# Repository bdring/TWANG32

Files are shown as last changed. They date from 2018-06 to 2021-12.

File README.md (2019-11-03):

# TWANG32
An ESP32 based, 1D, LED strip, dungeon crawler. inspired by Line Wobbler by Robin B

This was ported from the [TWANG fork](https://github.com/bdring/TWANG) by bdring of [Buildlog.net Blog](http://www.buildlog.net/blog?s=twang)

Youtube Video (https://www.youtube.com/watch?v=RXpfa-ZvUMA)

TWANG LED Game

## Why ESP32?
- Lower Cost than Arduino Mega
- Faster Processor
- More Memory
- Smaller (allows a smaller enclosure that is easier to print and more portable)
- DAC pins for better sound capabilities.
- WiFi and Bluetooth.

**Current State**

- All of the Arduino version game features are functional.
- The game now has a WiFi access port to get game stats. Connect a smartphone or computer to see them.
  - **SSID:** TWANG_AP
  - **Password:** 12345666
  - **URL:** 192.168.4.1
- You can update these settings over WiFi
  - LED Count
  - LED Brightness
  - Audio Volume
  - Joystick Deadzone (removes drift)
  - Attack Threshold (twang sensitivity)
  - Lives Per Level



## TO DO List:

- Wireless features~~
  - 2 Player features by linking controllers. TBD
=======
-  Settings:
  - Change strip type.
-  Digitized Audio
  - Currently the port uses the same square wave tones of the the Arduino version.
  - I want to convert to digitized high quality sound effects.
  - Possibly mix multiple sounds so things like lava and movement sound good at the same time.
- Better looking mobile web interface (looks more like a web app)

**BTW:** Since you have red this far... If you want to contribute, contact me and I might be able to get you some free or discounted hardware.

## Required libraries:
* [FastLED](http://fastled.io/)
* [RunningMedian](http://playground.arduino.cc/Main/RunningMedian)

## Hardware used:
* ESP32, I typically use the NodeMCU-32S module
* LED light strip. The more the better, maximum of 1000. Tested with 1x & 2x 144/meter, 12x 60/meter and 5m x 114/meter strips. This has been tested with APA102C and NeoPixel type strips. Anything compatible with the FastLED library should work.
* MPU6050 accelerometer
* Spring doorstop, I used [these](http://smile.amazon.com/gp/product/B00J4Y5BU2)
* Speaker and amplifier. I use a PAM8403 module. (ESP32 cannot drive a speaker as loudly as an Arduino)

See [Buildlog.net Blog](http://www.buildlog.net/blog?s=twang) for more details.

Super easy to use kits and ready to play units [are available on Tindie](https://www.tindie.com/products/33366583/twang32-led-strip-game/).

TWANG 32 Controller

## Enclosure
[The STL files are here](http://www.buildlog.net/blog/wp-content/uploads/2018/04/twang32_stl.zip).

TWANG32

## Overview
The following is a quick overview of the code to help you understand and tweak the game to your needs.

The game is played on a 1000 unit line, the position of enemies, the player, lava etc range from 0 to 1000 and the LEDs that represent them are derived using the `getLED()` function. You don't need to worry about this but it's good to know for things like the width of the attack and player max move speed. Regardless of the number of LEDs, everything takes place in this 1000 unit wide line.

**LED SETUP** Defines the quantity of LEDs as well as the data and clock pins used. I've tested several APA102-C strips and the color order sometimes changes from BGR to GBR, if the player is not blue, the exit green and the enemies red, this is the bit you want to change. Brightness should range from 50 to 255, use a lower number if playing at night or wanting to use a smaller power supply. `DIRECTION` can be set to 0 or 1 to flip the game orientation. In `setup()` there is a `FastLED.addLeds()` line, in there you could change it to another brand of LED strip like the cheaper WS2812.

The game also has 3 regular LEDs for life indicators (the player gets 3 lives which reset each time they level up). The pins for these LEDs are stored in `lifeLEDs[]` and are updated in the `updateLives()` function.

**JOYSTICK SETUP** All parameters are commented in the code, you can set it to work in both forward/backward as well as side-to-side mode by changing `JOYSTICK_ORIENTATION`. Adjust the `ATTACK_THRESHOLD` if the "Twanging" is overly sensitive and the `JOYSTICK_DEADZONE` if the player slowly drifts when there is no input (because it's hard to get the MPU6050 dead level).

**WOBBLE ATTACK** Sets the width, duration (ms) of the attack.

**POOLS** These are the object pools for enemies, particles, lava, conveyors etc. You can modify the quantity of any of them if your levels use more or if you want to save some memory, just remember to update the respective counts to avoid errors.

**USE_GRAVITY** 0/1 to set if particles created by the player getting killed should fall towards the start point, the `BEND_POINT` variable can be set to mark the point at which the strip of LEDs goes from being horizontal to vertical. The game is 1000 units wide (regardless of number of LED's) so 500 would be the mid point. If this is confusing just set `USE_GRAVITY` to 0.

## Modifying / Creating levels
Find the `loadLevel()` function, in there you can see a switch statement with the 10 levels I created.
They all call different functions and variables to setup the level. Each one is described below:

**playerPosition;** Where the player starts on the 0 to 1000 line. If not set it defaults to 0. I set it to 200 in the first level so the player can see movement even if the first action they take is to push the joystick left

**spawnEnemy(position, direction, speed, wobble);** (10 enemies max)
* position: 0 to 1000
* direction: 0/1, initial direction of travel
* speed: >=0, speed of the enemy, remember the game is 1000 wide and runs at 60fps. I recommend between 1 and 4
* wobble: 0=regular moving enemy, 1=sine wave enemy, in this case speed sets the width of the wave

**spawnPool[poolNumber].Spawn(position, rate, speed, direction);** (2 spawners max)
* A spawn pool is a point which spawns enemies forever
* position: 0 to 1000
* rate: milliseconds between spawns, 1000 = 1 second
* speed: speed of the enemis it spawns
* direction: 0=towards start, 1=away from start

**spawnLava(startPoint, endPoint, ontime, offtime, offset);** (4 lava pools max)
* startPoint: 0 to 1000
* endPoint: 0 to 1000, combined with startPoint this sets the location and size of the lava
* ontime: How long (ms) the lava is ON for
* offtime: How long the lava is ON for
* offset: How long (ms) after the level starts before the lava turns on, use this to create patterns with multiple lavas
* grow: This specifies the rate of growth. Use 0 for no growth. Reasonable growth is 0.1 to 0.5
* flow: This specifies the rate/direction of flow. Reasonable numbers are 0.2 to 0.8 

**spawnConveyor(startPoint, endPoint, speed);** (2 conveyors max)
* startPoint, endPoint: Same as lava
* speed: The direction and speed of the travel. Negative moves to base and positive moves towards exit. Must be less than +/- max player speed.

**spawnBoss();** (only one, don't edit boss level)
<<<<<<< HEAD
* There are no parameters for a boss, they always spawn in the same place and have 3 lives. Tweak the values of Boss.h to modify
=======
* There are no parameters for a boss, they always spawn in the same place and have 3 lives. Tweak the values of Boss.h to modify
>>>>>>> origin/master

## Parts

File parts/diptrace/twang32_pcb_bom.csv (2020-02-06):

RefDes | Value | Name | Manufacturer | Quantity
C1 | 1000uF 10V | UCL_size10x13.5 | Nichicon UCL1A102MNL1GS | 1
C2 | 0.47uF | CAP_NP_1206 |  | 1
C3 | 0.1uF | CAP_NP_1206 |  | 1
C4, C5, C8 | 1uF | CAP_NP_1206 |  | 3
C6, C7 | 10uF | CAP_NP_1206 |  | 2
D1 |  | 10BQ100 | Vishay SS2P2L-M3/84A | 1
J1 |  | PJ-007 | CUI | 1
J2 |  | HDR-1x2 |  | 1
R1, R2 | 10K | RES_1206 |  | 2
R3 | 1.5K | RES_1206 |  | 1
TB1, TB2 |  | TB_3p5mm_4POS |  | 2
U1 | ESP-32 | ESP-32 NodeMCU 32S |  | 1
U2 |  | PAM8403 | Diodes Inc | 1

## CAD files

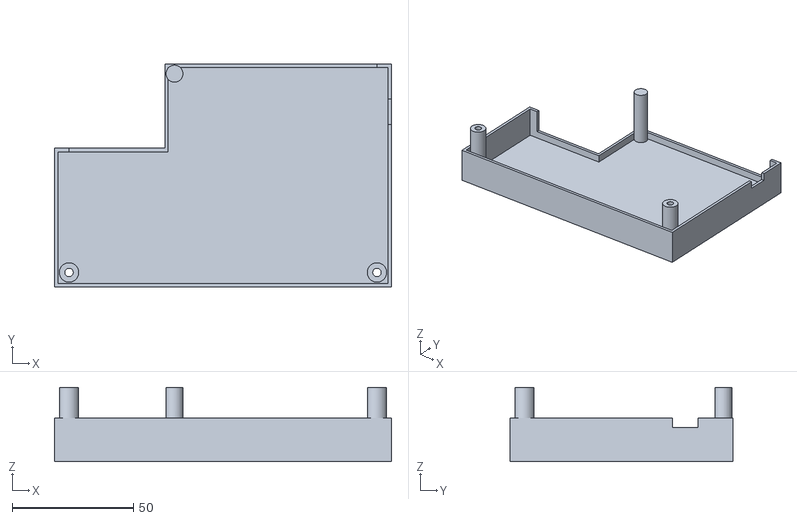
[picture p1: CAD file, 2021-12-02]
parts/stl/6_pack_cover_top.stl
139.0 x 92.0 x 30.6

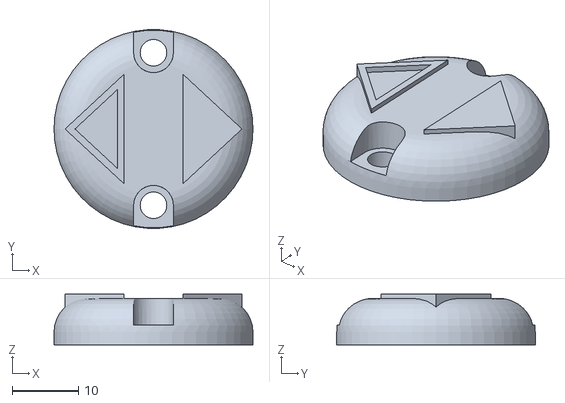
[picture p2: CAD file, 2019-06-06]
parts/stl/knob_cap2.stl
30.0 x 29.9 x 7.62

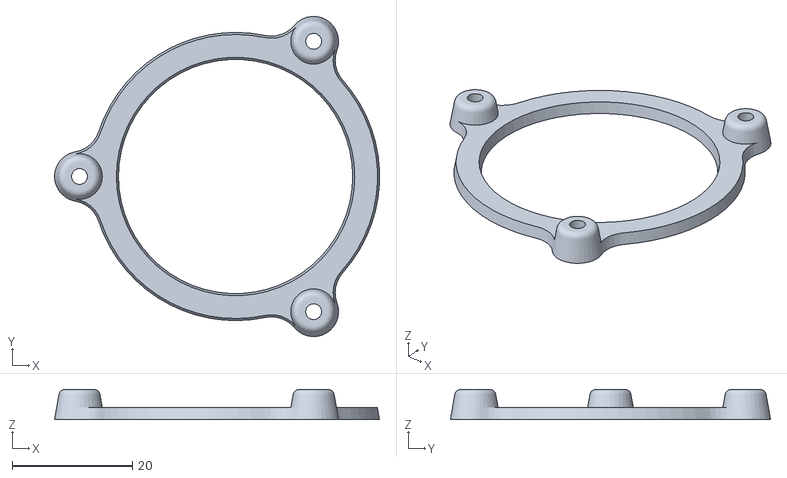
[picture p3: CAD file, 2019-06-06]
parts/stl/twang32_speaker_clamp.stl
54.1 x 53.3 x 5.00

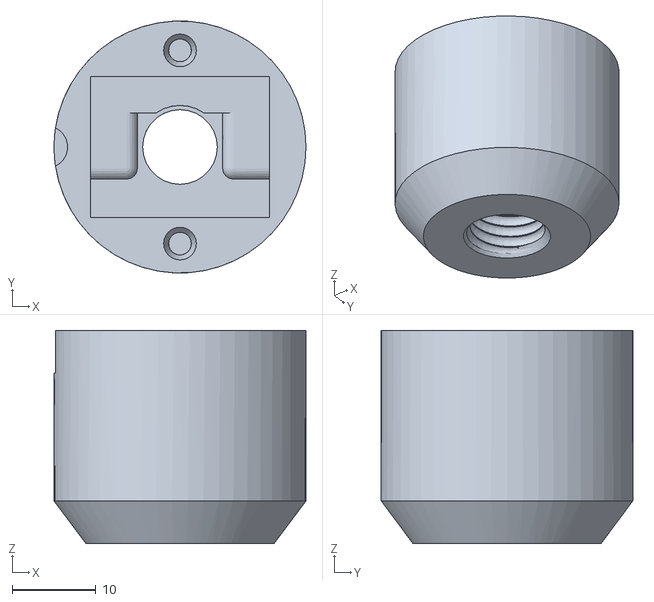
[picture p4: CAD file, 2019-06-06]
parts/stl/knob_bottom_2.stl
30.0 x 30.0 x 25.4

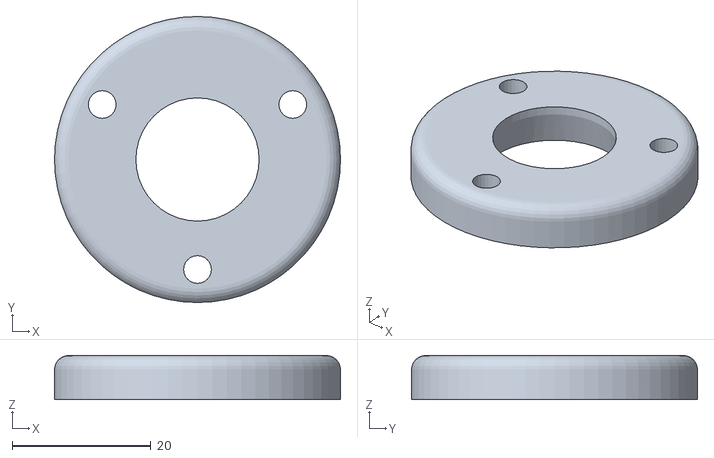
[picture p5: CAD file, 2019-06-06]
parts/stl/spring_clamp.stl
41.3 x 41.3 x 6.35

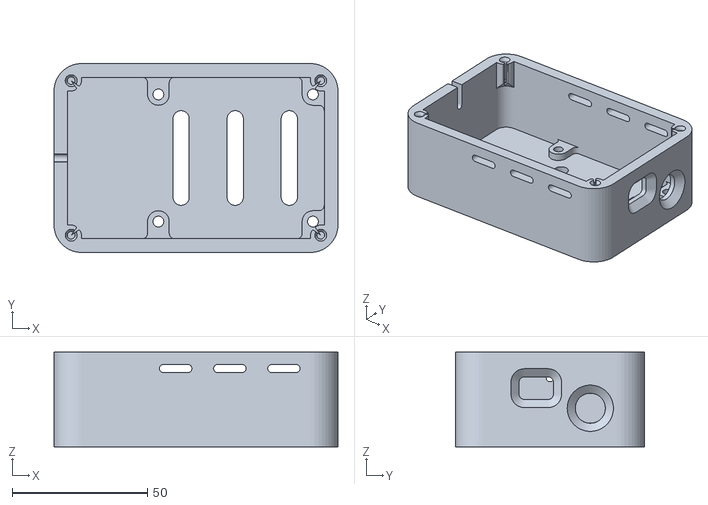
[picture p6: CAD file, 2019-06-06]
parts/stl/twang32_chassis.stl
105.0 x 69.8 x 35.0

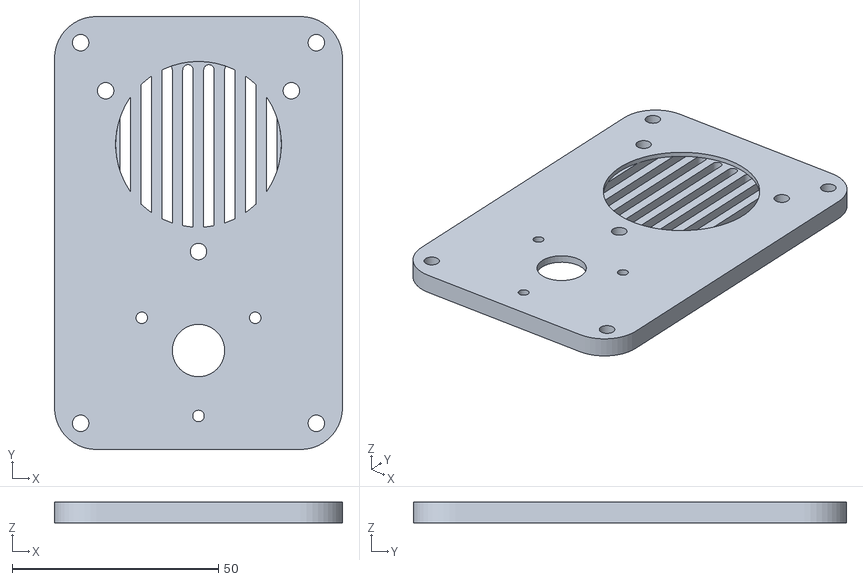
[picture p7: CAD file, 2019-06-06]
parts/stl/twang32_cover_2.stl
69.8 x 105.0 x 5.08

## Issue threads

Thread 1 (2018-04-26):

FastLED issue

sandman72, 2018-04-26:
The current official FastLED 3.1.6 library seems to cause watchdog reset issues here in my ESP32 setup (TTGO 32 R1 board, ESP32 rev1, Arduino ESP32 from Februray). I tried a workaround turning off interrupts during the FastLED .show() call with:

#define FASTLED_ALLOW_INTERRUPTS 0

but unfortunatly that breaks the sound output (loads of clickings during LED updates).
Could you check which versions of the Arduino Core ESP32 and FastLED libraries you are using, assuming everthing is working for you?

BTW: Awesome work! 😃

buildlog, 2018-04-26:
Sorry to hear you are having problems.

I am using FastLED 3.1.6. I am not sure how to tell the exact version of the ESP32 core, but my latest files are dated 3/14/2018. It runs fine for me on board NodeMCU-32S.  I have compiled it on several computers without issue. I don't know what happens when you choose different boards. What board are you compiling for? Did you change anything else in the firmware, like the #defines for the pins?

The only issue I had during development is that I had to turn off all Interrupts during EEPROM commits.

BTW: I am working on an ESP32 port of Grbl and am having problems with watchdog resets during interrupts. I have not solved that yet.

sandman72, 2018-04-27:
No, worries... WDT resets are quite common... usually a yield(); here and there will solve that... ;)
I had that issue with the FastLED library on the ESP32 before and could only get it to work stable with turning off interrupts... That usually breaks something else, in this case the sound part. I'll have a look over the weekend if I can find something...

sandman72, 2018-05-06:
I can confirm that this only happens with WS2812b based strips and their timing requirements. The APA102 strips work fine. No sound issues if you use these. For more infos: https://github.com/FastLED/FastLED/wiki/Interrupt-problems

afreeland, 2019-10-23:
I am using W2812B LEDs (300 count 16.4') and noticing what appears to be intermittent "freezing" of accelerometer data.  As in, the LEDs and game continue but the input from 🕹️ no longer seems to move the green dot... Until a hard power down.  Also the sound kind of had a pulsing/ticking that is always happening.

Was just curious if the interrupt issue would manifest itself in either of those ways?

Also I am using the esp-wroom-32 DoIt devkit v1 board, if that helps.

Hoping you may have some guidance here, thanks!

Closed 2018-05-06.

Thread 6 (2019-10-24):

Conveyor belt not working and lava not working properly..

yuppicide, 2019-10-24:
So I received my Twang32 prebuilt from you except for the LED wire. We tested it out using two APA102's. I adjusted brightness, sound volume, attack sensitivity, and 288 LED's. It was working fine. My friends had a blast with it!

I took it home and played a game or two and it was working fine. However, later that night I came back and the conveyor belt did not light up (invisible/lights off) but it still functions properly (pushes you backwards). The lava doesn't look like it used to. Instead of twinkling when it's safe to cross, it does not light up (invisible/lights off) but still functions properly (kills me).

Any ideas what is wrong here?

(Also, side note.. how come my lives (and your video on YouTube) show the lives on the bottom next to the controller, but this guy https://www.youtube.com/watch?v=pCQsKuKeDGg his is at the top of the LED strip)

yuppicide, 2019-10-24:
PS - I  have already tried recompiling and I have 2 more LED strips I tested. Same issue.. no conveyor or lava.

bdring, 2019-10-24:
Try increasing the brightness to full, just as a test.

yuppicide, 2019-10-25:
Already figured it out. I wish I would have figured it out before posting a
bug. 35 brightness shows.. I'm not sure the exact number but 25 definitely
doesn't show.

I was playing in the house and didn't wanna bother anyone is why I had it
down.

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

bdring, 2019-10-25:
I have seen that on WS2812 strips, but not on APA102 strips, so i guessed that might be it. The brightness is a global thing and some of the lighter items drop out first.

In [config.h](https://github.com/bdring/TWANG32/blob/master/TWANG32/config.h#L50) you will see some compensation values for the strip types. These were chosen for the strips I tested. You could tweak those values if need be.

bdring, 2019-10-25:
Also, you will probably never be able to use the full range of the brightness on all strip types. Something will drop out first.

Closed 2019-10-25.

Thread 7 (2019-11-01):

Accelerometer data freezes

afreeland, 2019-11-01:
I have been seeing an issue where, what appears to be randomly, the accelerometer data just stops working with the game. The green LED player will just stop moving...all other neopixel leds still work (enemies move, lava flows, death animation works, random led sequence post game). Once the game stops accepting accelerometer input, nothing seems to fix it but a hard power reboot.  I have triple checked the cabling to ensure no shorts...tried various accelerometer chips but with no luck.

I seen another [issue on interrupts](https://github.com/bdring/TWANG32/issues/1#issuecomment-545228889) and was sure if that was related or not.  Just looking for any guidance on how to test or if you have seen this issue.

Hardware:
- DOIT Esp32 DevKit v1 board
- [WS2812B](https://www.amazon.com/gp/product/B01LSF4Q0A/ref=ppx_yo_dt_b_asin_title_o04_s01?ie=UTF8&psc=1) NeoPixels
- [MPU6050](https://www.amazon.com/gp/product/B00LP25V1A/ref=ppx_yo_dt_b_asin_title_o03_s00?ie=UTF8&psc=1)

I did see the debug lines for serial and will try that...I mounted LEDs to a wall already and it makes the reading of serial a little trickier now.  I probably should of worked out the kinks before going all in lol :)
https://github.com/bdring/TWANG32/blob/0ef73584328d7b5b7d4b6bc1e1dc2b60e992db4c/TWANG32/TWANG32.ino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

bdring, 2019-11-02:
I have seen lock ups, but quite rarely. I can have it running for hours without issue.

I wonder if you go a few loops without proper data, the gyro could be re-initialized

```C++
accelgyro.initialize();
```

I have not played with the code in a while, but recently thought of some new level ideas. I thought some lava options could be tried. If it flowed or grew, it could create some urgency to complete levels.  I might give another look at the accel code then.

afreeland, 2019-11-02:
Thanks for the response and will look into the `initialize()` code.  I wish I wasn't so garbage at c/c++ or I could help...if this was like C#, JS, Go, Python...anything else lol.  I am just so terribly slow with c++.

The Lava _flowing_ sounds like a really cool improvement and forcing urgency would be a great addition.

You ever noticed any feedback to audio from wifi?  I am using [Adafruit Mono 2.5w amp](https://www.adafruit.com/product/2130) and have noticed that I get this constant ticking audio.  I see the blips in the oscilliscope and I cant seem to track down what is causing it...I put my finger over the wireless antenna and noticed that the _ticking_ was greatly reduced (barely audible).  They are side by side on the board and thought that may be causing me some issues.

bdring, 2019-11-02:
I have not heard any ticking sounds. Try switching DAC outputs. How wide is the tick on the scope? Could you filter it? I use the [PAM8403](https://www.aliexpress.com/item/1822706737.html)

I think an early level with lava moving down would be a good introduction. Lava growing from the bottom would be a great way to push you along. Lava growing in the middle would eventually be to wide to cross and force death near the bottom.

afreeland, 2019-11-02:
> I have not heard any ticking sounds. Try switching DAC outputs. How wide is the tick on the scope? Could you filter it? I use the [PAM8403](https://www.aliexpress.com/item/1822706737.html)
>
> I think an early level with lava moving down would be a good introduction. Lava growing from the bottom would be a great way to push you along. Lava growing in the middle would eventually be to wide to cross and force death near the bottom.

So was just doing some serial monitor debugging and trying to identify the issues with the accelerometer.  I got distracted by the ticking sound and swapped out DAC pin 25 for 26 and was still hearing it.  I was really suspicious of the wifi module since when I press on the antenna the ticking almost disappears.

Commented out this line just to try: https://github.com/bdring/TWANG32/blob/master/TWANG32/TWANG32.ino#L226

Sure enough the ticking is now gone but so would my webserver.  I may throw a different esp32 at it and see if that helps and when I build the stand for the twang stick I may put some distance between the audio amp/speaker and the board.  Just figured I would give an update on that very strange issue.  Not sure if its an interference issue or something with how the wifi lib operates...but I am guessing interference since you have not seen that issue.

bdring, 2019-11-02:
Thanks for the update. Nice job isolating it to the wifi.

I will probably start looking at the accel and lava code on Monday.

bdring, 2019-11-02:
If you turn of the serial debugging and have a screen lockup. Tell me what the values are.

bdring, 2019-11-03:
I got some time and added the flowing and growing lava. It really adds a sense of panic to some levels. I added a few new levels with various implementations.  I'll push the changes tomorrow.

**BTW:** I had it running for about 2 hours while writing and testing with no lockups.

Closed 2020-02-06.

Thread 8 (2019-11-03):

New Lava Features and Levels

bdring, 2019-11-03:
Someone suggested lava could be enhanced, so I added flow and growth parameters. Now the lava can flow at any desired rate and direction. It can also grow in size.

Combined with the on/off times, you can create some **pretty intense levels**. You could place lava at the bottom with a short off time and have it push you towards the top. Lava could also grow at a rate that you need to cross it and get off the level quickly. It can be very distracting to have the lava chasing you from behind and enemies attacking from above.

I added 4 new levels to introduce the features.

Happy Twanging!

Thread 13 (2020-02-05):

Component List

diegotheslinger, 2020-02-05:
Hello, was wondering if anyone knew where to find a component list for this project?  Saw the kit is unavailable from tindie.  I already have the board printed out, just wondering on component sizes as im not super familiar with surface mount packages.

Thank You.

bdring, 2020-02-05:
I can do that in a few days.

diegotheslinger, 2020-02-05:
Wow thank you that would be helpful!

bdring, 2020-02-06:
[Here is what I have](https://github.com/bdring/TWANG32/blob/master/parts/diptrace/twang32_pcb_bom.csv)

Closed 2020-02-06.

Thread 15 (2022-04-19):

Audio only in the first game

zenturacp, 2022-04-19:
Hi - i have created a Twang32 and it works almost the sound is only in the first game...

When I reset the device it works again but never in subsequent games?

zenturacp, 2022-04-21:
https://github.com/bdring/TWANG32/blob/a848394748c9df7516cd4b9a902e994b4a067f36/TWANG32/sound.h#L59

The issue is somehow related to the pause of the audio - it really only is an issue when writing to the EEPROM and it disables the sound / interrupts.. It seems like the sound_resume is not working as expected

It could be related to the ESP32 chip - frequency something?

zenturacp, 2022-04-22:
The issue is "resolved" you have to use ESP32 < version 2.x - 1.0.6 works fine

neilferreri, 2025-01-19:
I fixed this for ESP32 v3.1.1 in my fork.
https://github.com/neilferreri/TWANG32

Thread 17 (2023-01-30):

Low / No gravity jet pack mode?

mylesdebastion, 2023-01-30:
Any interest in adding a node for low / no gravity? Would be happy to sponsor this request!
* create movement mode to make the player (green LED) glide with frictionless inertia to simulate no gravity
* add small flame animation effect like a jet pack behind the green led (flame should switch to front or back when reversing direction of movement)

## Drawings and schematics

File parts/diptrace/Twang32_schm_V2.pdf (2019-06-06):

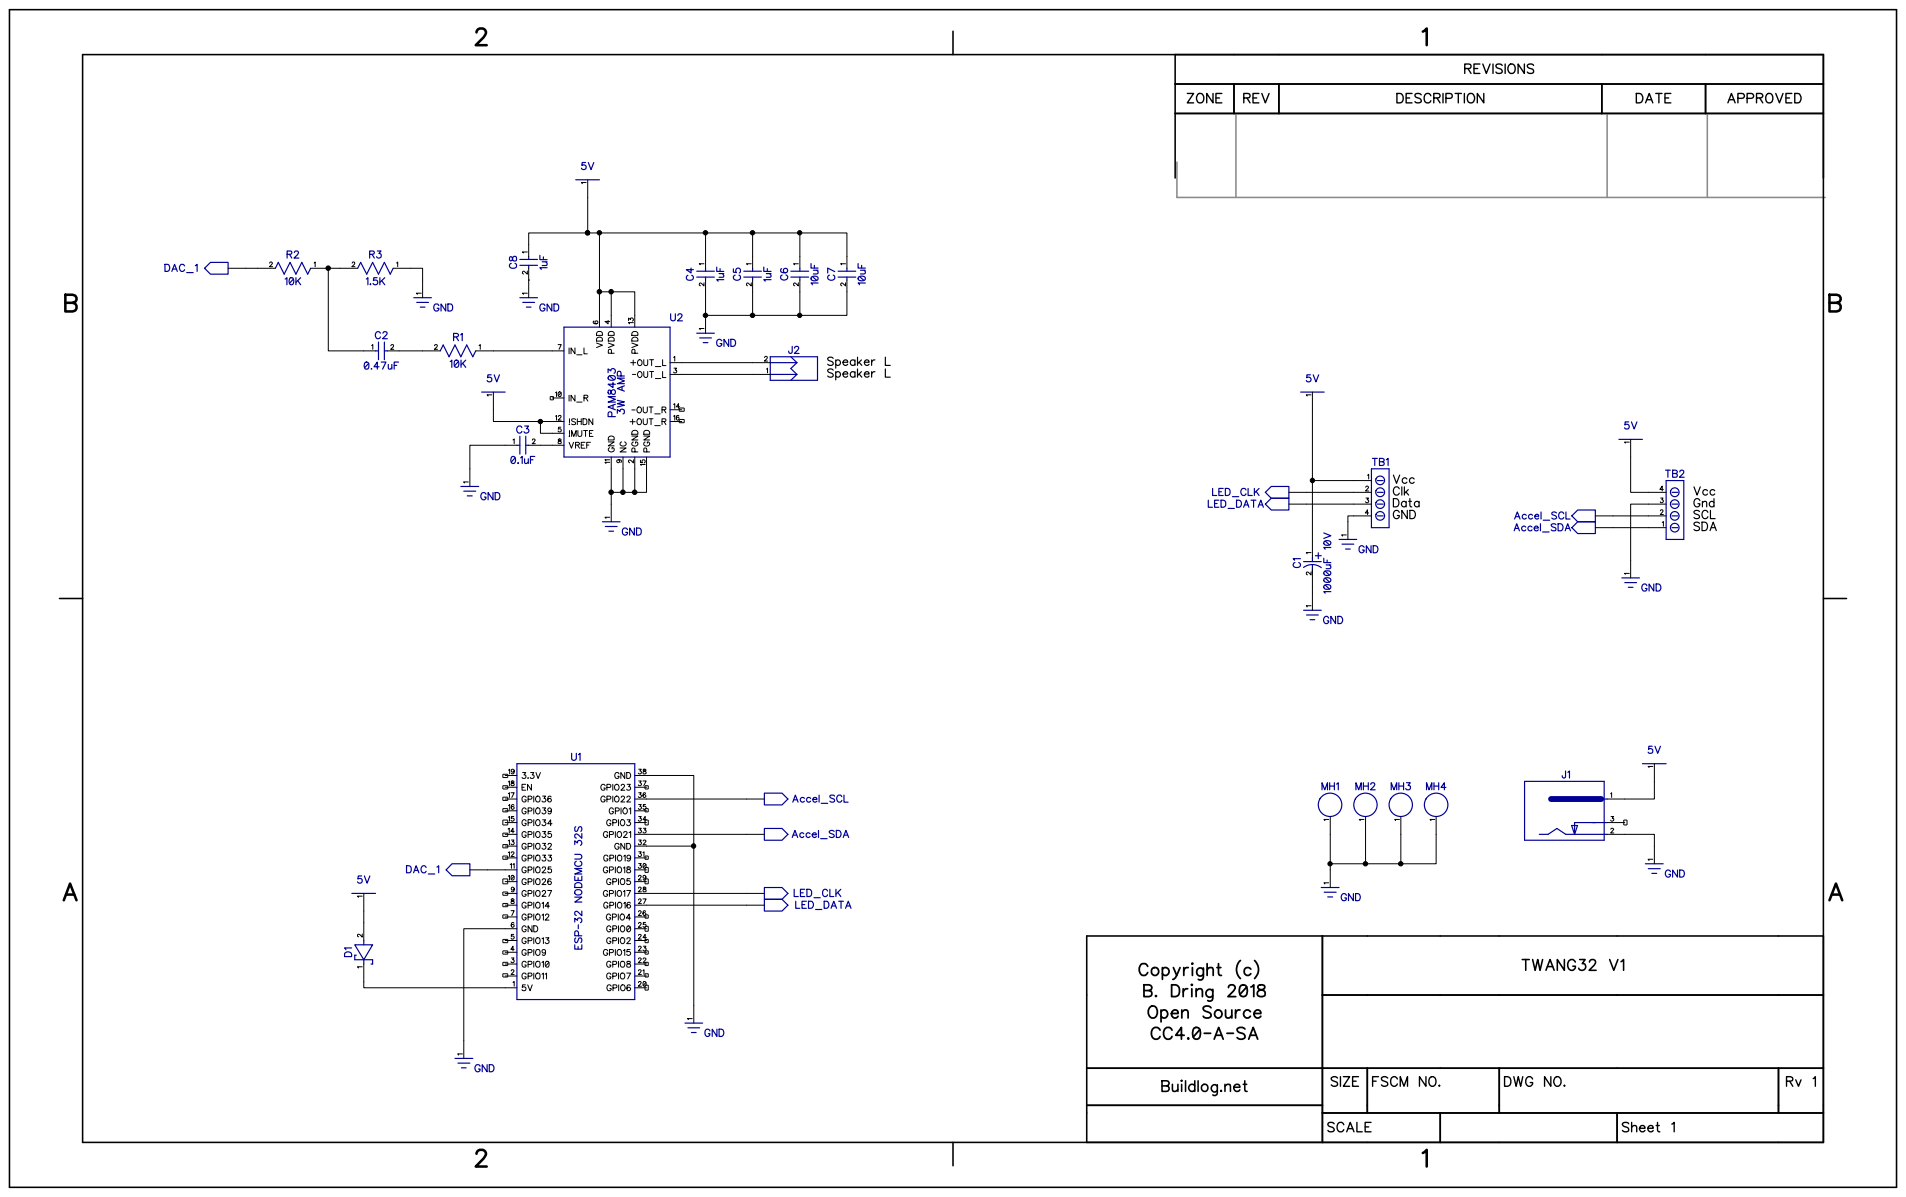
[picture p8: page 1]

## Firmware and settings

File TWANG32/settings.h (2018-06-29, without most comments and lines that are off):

	#define SETTINGS_H
#include <EEPROM.h>
#include "sound.h"
#define SETTINGS_VERSION 2
#define EEPROM_SIZE				   256
#define NUM_LEDS        144
#define MIN_LEDS				60
#define DEFAULT_BRIGHTNESS	150
#define MIN_BRIGHTNESS			10
#define MAX_BRIGHTNESS 			255
const uint8_t MAX_PLAYER_SPEED = 10;     // Max move speed of the player
const uint8_t LIVES_PER_LEVEL = 3;      // default lives per level
#define MIN_LIVES_PER_LEVEL 3
#define MAX_LIVES_PER_LEVEL 9
#define JOYSTICK_ORIENTATION 1     // 0, 1 or 2 to set the axis of the joystick
#define JOYSTICK_DIRECTION   1     // 0/1 to flip joystick direction
#define DEFAULT_ATTACK_THRESHOLD     30000 // The threshold that triggers an attack
#define MIN_ATTACK_THRESHOLD     20000
#define MAX_ATTACK_THRESHOLD     30000
#define DEFAULT_JOYSTICK_DEADZONE    8     // Angle to ignore
#define MIN_JOYSTICK_DEADZONE 3
#define MAX_JOYSTICK_DEADZONE 12
#define DEFAULT_VOLUME          20     // 0 to 255
#define MIN_VOLUME							0
#define MAX_VOLUME							255
#define DAC_AUDIO_PIN 		25     // should be 25 or 26 only
enum ErrorNums{
	ERR_SETTING_NUM,
	ERR_SETTING_RANGE
};
long lastInputTime = 0;
void settings_init();
void show_game_stats();
void settings_eeprom_write();
void settings_eeprom_read();
void change_setting_serial(char *line);
void processSerial(char inChar);
void printError(int reason);
void show_settings_menu();
void reset_settings();
void change_setting(char paramCode, uint16_t newValue);
SemaphoreHandle_t xMutex;
typedef struct {
	uint8_t settings_version; // stores the settings format version
	uint16_t led_count;
	uint8_t led_brightness;
	uint8_t joystick_deadzone;
	uint16_t attack_threshold;
	uint8_t audio_volume;
	uint8_t lives_per_level;
	uint16_t games_played;
	uint32_t total_points;
	uint16_t high_score;
	uint16_t boss_kills;
}settings_t;
settings_t user_settings;
#define READ_BUFFER_LEN 10
#define CARRIAGE_RETURN 13
char readBuffer[READ_BUFFER_LEN];
uint8_t readIndex = 0;
void settings_init() {
	settings_eeprom_read();
	show_settings_menu();
	show_game_stats();
}
void checkSerialInput() {
	if (Serial.available()) {
		processSerial(Serial.read());
	}
}
void processSerial(char inChar)
{
	readBuffer[readIndex] = inChar;
		switch(readBuffer[readIndex]){
			case '?':
				readIndex = 0;
				show_game_stats();
				show_settings_menu();
				return;
			break;
			case 'R':
				readIndex = 0;
				reset_settings();
				settings_eeprom_write();
				return;
			break;
			case 'P':
				user_settings.games_played = 0;
				user_settings.total_points = 0;
				user_settings.high_score = 0;
				user_settings.boss_kills = 0;
				settings_eeprom_write();
				return;
			break;
			case '!':
				ESP.restart();
			default:
			break;
		}
		if (readBuffer[readIndex] == CARRIAGE_RETURN) {
			if (readIndex < 3) {
				readIndex = 0;
			}
			else {
				readBuffer[readIndex] = 0; // mark it as the end of the string
				change_setting_serial(readBuffer);
				readIndex = 0;
			}
		}
		else if (readIndex >= READ_BUFFER_LEN) {
			readIndex = 0; // too many characters. Reset and try again
		}
		else
			readIndex++;
}
void change_setting_serial(char *line) {
  char setting_val[6];
  char param;
  uint16_t newValue;
  if (readBuffer[1] != '='){  // check if the equals sign is there
	Serial.print("Missing '=' in command");
	readIndex = 0;
	return;
  }
  for(int i=0; i<5; i++) {
	if (i+2 < readIndex) {
		if (isDigit(readBuffer[i+2]))
			setting_val[i] = readBuffer[i+2];
		else {
			Serial.println("Invalid setting value");
			return;
		}
	}
	else
		setting_val[i] = 0;
  }
  param = readBuffer[0];
  newValue = atoi(setting_val); // convert the val section to an integer
  memset(readBuffer,0,sizeof(readBuffer));
	change_setting(param, newValue);
}
void change_setting(char paramCode, uint16_t newValue)
{
	switch (paramCode) {
		lastInputTime = millis(); // reset screensaver count
		case 'C': // LED Count
				user_settings.led_count = constrain(newValue, MIN_LEDS, MAX_LEDS);
				settings_eeprom_write();
		break;
		case 'B': // brightness
			user_settings.led_brightness = constrain(newValue, MIN_BRIGHTNESS, MAX_BRIGHTNESS);
			FastLED.setBrightness(user_settings.led_brightness);
			settings_eeprom_write();
		break;
		case 'S': // sound
			user_settings.audio_volume = constrain(newValue, MIN_VOLUME, MAX_VOLUME);
			settings_eeprom_write();
		break;
		case 'D': // deadzone, joystick
			user_settings.joystick_deadzone = constrain(newValue, MIN_JOYSTICK_DEADZONE, MAX_JOYSTICK_DEADZONE);
			settings_eeprom_write();
		break;
		case 'A': // attack threshold, joystick
			user_settings.attack_threshold = constrain(newValue, MIN_ATTACK_THRESHOLD, MAX_ATTACK_THRESHOLD);
			settings_eeprom_write();
		break;
		case 'L': // lives per level
			user_settings.lives_per_level = constrain(newValue, MIN_LIVES_PER_LEVEL, MAX_LIVES_PER_LEVEL);
			settings_eeprom_write();
		break;
		default:
			Serial.print("Command Error: ");
			Serial.println(readBuffer[0]);
			return;
		break;
  }
	show_settings_menu();
}
void reset_settings() {
	user_settings.settings_version = SETTINGS_VERSION;
	user_settings.led_count = NUM_LEDS;
	user_settings.led_brightness = DEFAULT_BRIGHTNESS;
	user_settings.joystick_deadzone = DEFAULT_JOYSTICK_DEADZONE;
	user_settings.attack_threshold = DEFAULT_ATTACK_THRESHOLD;
	user_settings.audio_volume = DEFAULT_VOLUME;
	user_settings.lives_per_level = LIVES_PER_LEVEL;
	user_settings.games_played = 0;
	user_settings.total_points = 0;
	user_settings.high_score = 0;
	user_settings.boss_kills = 0;
	Serial.println("Settings reset...");
	settings_eeprom_write();
}
void show_settings_menu() {
	Serial.println("\r\n====== TWANG Settings Menu ========");
	Serial.println("=    Current values are shown     =");
	Serial.println("=   Send new values like B=150    =");
	Serial.println("=     with a carriage return      =");
	Serial.println("===================================");
	Serial.print("\r\nC=");
	Serial.print(user_settings.led_count);
	Serial.print(" (LED Count 60-");
	Serial.print(MAX_LEDS);
	Serial.println(")");
	Serial.print("B=");
	Serial.print(user_settings.led_brightness);
	Serial.println(" (LED Brightness 5-255)");
	Serial.print("S=");
	Serial.print(user_settings.audio_volume);
	Serial.println(" (Sound Volume 0-255)");
	Serial.print("D=");
	Serial.print(user_settings.joystick_deadzone);
	Serial.println(" (Joystick Deadzone 3-12)");
	Serial.print("A=");
	Serial.print(user_settings.attack_threshold);
	Serial.println(" (Attack Sensitivity 20000-35000)");
	Serial.print("L=");
	Serial.print(user_settings.lives_per_level);
	Serial.println(" (Lives per Level (3-9))");
	Serial.println("\r\n(Send...)");
	Serial.println("  ? to show current settings");
	Serial.println("  R to reset everything to defaults)");
	Serial.println("  P to reset play statistics)");
}
void show_game_stats()
{
	Serial.println("\r\n===== Play statistics ======");
	Serial.print("Games played: ");Serial.println(user_settings.games_played);
	if (user_settings.games_played > 0)	{
		Serial.print("Average Score: ");Serial.println(user_settings.total_points / user_settings.games_played);
	}
	Serial.print("High Score: ");Serial.println(user_settings.high_score);
	Serial.print("Boss kills: ");Serial.println(user_settings.boss_kills);
}
void settings_eeprom_read()	{
	EEPROM.begin(EEPROM_SIZE);
	uint8_t ver = EEPROM.read(0);
	uint8_t temp[sizeof(user_settings)];
	if (ver != SETTINGS_VERSION) {
		Serial.print("Error: EEPROM settings read failed:"); Serial.println(ver);
		Serial.println("Loading defaults...");
		EEPROM.end();
		reset_settings();
		return;
	}
	else {
		Serial.print("Settings version: "); Serial.println(ver);
	}
	for (int i=0; i<sizeof(user_settings); i++)
	{
		temp[i] = EEPROM.read(i);
	}
	EEPROM.end();
	memcpy((char*)&user_settings, temp, sizeof(user_settings));
}
void settings_eeprom_write() {
	sound_pause(); // prevent interrupt from causing crash
	EEPROM.begin(EEPROM_SIZE);
	uint8_t temp[sizeof(user_settings)];
	memcpy(temp, (uint8_t*)&user_settings, sizeof(user_settings));
	for (int i=0; i<sizeof(user_settings); i++)
	{
		EEPROM.write(i, temp[i]);
	}
	EEPROM.commit();
	EEPROM.end();
	sound_resume(); // restore sound interrupt
}
void printError(int reason) {
	switch(reason) {
		case ERR_SETTING_NUM:
			Serial.print("Error: Invalid setting number");
		break;
		case ERR_SETTING_RANGE:
			Serial.print("Error: Setting out of range");
		break;
		default:
			Serial.print("Error:");Serial.println(reason);
		break;
	}
}

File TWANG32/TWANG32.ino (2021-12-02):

/*
	TWANG32 - An ESP32 port of TWANG
	(c) B. Dring 3/2018
	License: Creative Commons 4.0 Attribution - Share Alike	
	
	TWANG was originally created by Critters
	https://github.com/Critters/TWANG
	
	It was inspired by Robin Baumgarten's Line Wobbler Game
	
	Recent Changes
	- Updated to move FastLEDshow to core 0
	Fixed Neopixel
	  - Used latest FastLED library..added compile check
		- Updated to move FastLEDshow to core 0
		- Reduced MAX_LEDS on Neopixel
		- Move some defines to a separate config.h file to make them accessible to other files
	- Changed volume typo on serial port settings menu	

	Project TODO
		- Make the strip type configurable via serial and wifi
	
		
	Usage Notes:
		- Changes to LED strip and other hardware are in config.h
		- Change the strip type to what you are using and compile/load firmware
		- Use Serial port or Wifi to set your strip length.	
*/

// 

#define VERSION "2018-06-28"

#include <FastLED.h>
#include<Wire.h>
#include "Arduino.h"
#include "RunningMedian.h"

// twang files
#include "config.h"
#include "twang_mpu.h"
#include "enemy.h"
#include "particle.h"
#include "spawner.h"
#include "lava.h"
#include "boss.h"
#include "conveyor.h"
#include "iSin.h"
#include "sound.h"
#include "settings.h"
#include "wifi_ap.h"

#if defined(FASTLED_VERSION) && (FASTLED_VERSION < 3001000)
	#error "Requires FastLED 3.1 or later; check github for latest code."
#endif



#define DIRECTION            1
#define USE_GRAVITY          0     // 0/1 use gravity (LED strip going up wall)
#define BEND_POINT           550   // 0/1000 point at which the LED strip goes up the wall

// GAME
long previousMillis = 0;           // Time of the last redraw
int levelNumber = 0;

#define TIMEOUT              20000  // time until screen saver in milliseconds

int joystickTilt = 0;              // Stores the angle of the joystick
int joystickWobble = 0;            // Stores the max amount of acceleration (wobble)

// WOBBLE ATTACK
#define DEFAULT_ATTACK_WIDTH 70  // Width of the wobble attack, world is 1000 wide
int attack_width = DEFAULT_ATTACK_WIDTH;     
#define ATTACK_DURATION     500    // Duration of a wobble attack (ms)
long attackMillis = 0;             // Time the attack started
bool attacking = 0;                // Is the attack in progress?   
#define BOSS_WIDTH          40

// TODO all animation durations should be defined rather than literals 
// because they are used in main loop and some sounds too.
#define STARTUP_WIPEUP_DUR 200
#define STARTUP_SPARKLE_DUR 1300
#define STARTUP_FADE_DUR 1500

#define GAMEOVER_SPREAD_DURATION 1000
#define GAMEOVER_FADE_DURATION 1500

#define WIN_FILL_DURATION 500     // sound has a freq effect that might need to be adjusted
#define WIN_CLEAR_DURATION 1000
#define WIN_OFF_DURATION 1200

Twang_MPU accelgyro = Twang_MPU();
CRGB leds[VIRTUAL_LED_COUNT];
RunningMedian MPUAngleSamples = RunningMedian(5);
RunningMedian MPUWobbleSamples = RunningMedian(5);
iSin isin = iSin();

//#define JOYSTICK_DEBUG  // comment out to stop serial debugging

// POOLS
#define LIFE_LEDS 3
int lifeLEDs[LIFE_LEDS] = {7, 6, 5}; // these numbers are Arduino GPIO numbers...this is not used in the B. Dring enclosure design

#define ENEMY_COUNT 10
Enemy enemyPool[ENEMY_COUNT] = {
    Enemy(), Enemy(), Enemy(), Enemy(), Enemy(), Enemy(), Enemy(), Enemy(), Enemy(), Enemy()
};


#define PARTICLE_COUNT 100
Particle particlePool[PARTICLE_COUNT] = {
    Particle(), Particle(), Particle(), Particle(), Particle(), Particle(), Particle(), Particle(), Particle(), Particle(), Particle(), Particle(), Particle(), Particle(), Particle(), Particle(), Particle(), Particle(), Particle(), Particle(), Particle(), Particle(), Particle(), Particle(), Particle(), Particle(), Particle(), Particle(), Particle(), Particle(), Particle(), Particle(), Particle(), Particle(), Particle(), Particle(), Particle(), Particle(), Particle(), Particle()
};

#define SPAWN_COUNT 5
Spawner spawnPool[SPAWN_COUNT] = {
    Spawner(), Spawner()
};

#define LAVA_COUNT 5
Lava lavaPool[LAVA_COUNT] = {
    Lava(), Lava(), Lava(), Lava()
};

#define CONVEYOR_COUNT 2
Conveyor conveyorPool[CONVEYOR_COUNT] = {
    Conveyor(), Conveyor()
};

Boss boss = Boss();

enum stages {
	STARTUP,
	PLAY,
	WIN,
	DEAD,
	SCREENSAVER,
	BOSS_KILLED,
	GAMEOVER
} stage;

long stageStartTime;               // Stores the time the stage changed for stages that are time based
int playerPosition;                // Stores the player position
int playerPositionModifier;        // +/- adjustment to player position
bool playerAlive;
long killTime;
int lives = LIVES_PER_LEVEL; 
bool lastLevel = false;

int score = 0;

#define FASTLED_SHOW_CORE 0  // -- The core to run FastLED.show()

// -- Task handles for use in the notifications
static TaskHandle_t FastLEDshowTaskHandle = 0;
static TaskHandle_t userTaskHandle = 0;

/** show() for ESP32
 *  Call this function instead of FastLED.show(). It signals core 0 to issue a show, 
 *  then waits for a notification that it is done.
 */
void FastLEDshowESP32()
{
    if (userTaskHandle == 0) {
        // -- Store the handle of the current task, so that the show task can
        //    notify it when it's done
        userTaskHandle = xTaskGetCurrentTaskHandle();

        // -- Trigger the show task
        xTaskNotifyGive(FastLEDshowTaskHandle);

        // -- Wait to be notified that it's done
        const TickType_t xMaxBlockTime = pdMS_TO_TICKS( 200 );
        ulTaskNotifyTake(pdTRUE, xMaxBlockTime);
        userTaskHandle = 0;
    }
}

/** show Task
 *  This function runs on core 0 and just waits for requests to call FastLED.show()
 */
void FastLEDshowTask(void *pvParameters)
{
    // -- Run forever...
    for(;;) {
        // -- Wait for the trigger
        ulTaskNotifyTake(pdTRUE, portMAX_DELAY);

        // -- Do the show (synchronously)
        FastLED.show();

        // -- Notify the calling task
        xTaskNotifyGive(userTaskHandle);
    }
}


void setup() {
	Serial.begin(115200);
	Serial.print("\r\nTWANG32 VERSION: "); Serial.println(VERSION);	
	
	settings_init();	// load the user settings from EEPROM
	
	Wire.begin();
	accelgyro.initialize();
	
#ifdef USE_NEOPIXEL
  Serial.print("\r\nCompiled for WS2812B (Neopixel) LEDs");
  FastLED.addLeds<LED_TYPE, DATA_PIN>(leds, MAX_LEDS);
#endif

#ifdef USE_APA102
  Serial.print("\r\nCompiled for APA102 (Dotstar) LEDs");
  FastLED.addLeds<LED_TYPE, DATA_PIN, CLOCK_PIN, LED_COLOR_ORDER>(leds, MAX_LEDS);
#endif
 
	FastLED.setBrightness(user_settings.led_brightness);
	FastLED.setDither(1);
	
	// -- Create the ESP32 FastLED show task
  xTaskCreatePinnedToCore(FastLEDshowTask, "FastLEDshowTask", 2048, NULL, 2, &FastLEDshowTaskHandle, FASTLED_SHOW_CORE); 

	sound_init(DAC_AUDIO_PIN);
	
	ap_setup();

	stage = STARTUP;
	stageStartTime = millis();
	lives = user_settings.lives_per_level;
	
}

void loop() {
  long mm = millis();
  int brightness = 0;  
    
  ap_client_check(); // check for web client
  checkSerialInput();

  if(stage == PLAY){
      if(attacking){
          SFXattacking();
      }else{
          SFXtilt(joystickTilt);
					
					
      }
  }else if(stage == DEAD){
      SFXdead();
  }

  if (mm - previousMillis >= MIN_REDRAW_INTERVAL) {
      getInput(); 

      
      
      long frameTimer = mm;
      previousMillis = mm;

      if(abs(joystickTilt) > user_settings.joystick_deadzone){
            lastInputTime = mm;
            if(stage == SCREENSAVER){
                levelNumber = -1;
                stageStartTime = mm;
                stage = WIN;
            }
        }else{
            if(lastInputTime+TIMEOUT < mm){        
                stage = SCREENSAVER;
            }
        }


        
        if(stage == SCREENSAVER){
            screenSaverTick();    
        }else if(stage == STARTUP){
			if (stageStartTime+STARTUP_FADE_DUR > mm) {
				tickStartup(mm);
			}
			else
			{
			SFXcomplete();
			levelNumber = 0;
			loadLevel();
			}
		}else if(stage == PLAY){
            // PLAYING
            if(attacking && attackMillis+ATTACK_DURATION < mm) attacking = 0;

            // If not attacking, check if they should be
            if(!attacking && joystickWobble >= user_settings.attack_threshold){
                attackMillis = mm;
                attacking = 1;
            }

            // If still not attacking, move!
            playerPosition += playerPositionModifier;
            if(!attacking){
								SFXtilt(joystickTilt);
                //int moveAmount = (joystickTilt/6.0);  // 6.0 is ideal at 16ms interval (6.0 / (16.0 / MIN_REDRAW_INTERVAL))
								int moveAmount = (joystickTilt/(6.0));  // 6.0 is ideal at 16ms interval 
                if(DIRECTION) moveAmount = -moveAmount;
                moveAmount = constrain(moveAmount, -MAX_PLAYER_SPEED, MAX_PLAYER_SPEED);
								
                playerPosition -= moveAmount;
                if(playerPosition < 0) 
					playerPosition = 0;
        
				// stop player from leaving if boss is alive
				if (boss.Alive() && playerPosition >= VIRTUAL_LED_COUNT) // move player back
					playerPosition = 999; //(user_settings.led_count - 1) * (1000.0/user_settings.led_count);
          
                if(playerPosition >= VIRTUAL_LED_COUNT && !boss.Alive()) {
                    // Reached exit!
                    levelComplete();
                    return;
                }
            }

            if(inLava(playerPosition)){
                die();
            }

            // Ticks and draw calls
            FastLED.clear();
            tickConveyors();
            tickSpawners();
            tickBoss();
            tickLava();
            tickEnemies();
            drawPlayer();      
            drawAttack();
            drawExit();
        }else if(stage == DEAD){
            // DEAD
            FastLED.clear();
			tickDie(mm);
            if(!tickParticles()){
                loadLevel();
            }
        }else if(stage == WIN){
            // LEVEL COMPLETE     
            tickWin(mm);
        }else if(stage == BOSS_KILLED){
					tickBossKilled(mm);					   
         } else if (stage == GAMEOVER) {
						if (stageStartTime+GAMEOVER_FADE_DURATION > mm)
						{				 
							tickGameover(mm);
						}
						else
						{
						FastLED.clear(); 
						save_game_stats(false);		// boss not killed
						
						// restart from the beginning
						stage = STARTUP;
						stageStartTime = millis();
						lives = user_settings.lives_per_level;						
						
						}          
         }        

      //FastLED.show();
			FastLEDshowESP32();

  }

  
}

// ---------------------------------
// ------------ LEVELS -------------
// ---------------------------------
void loadLevel(){    	
	// leave these alone
	FastLED.setBrightness(user_settings.led_brightness);
	updateLives();
	cleanupLevel();    
	playerAlive = 1;
	lastLevel = false; // this gets changed on the boss level
	
	/// Defaults...OK to change the following items in the levels below
	attack_width = DEFAULT_ATTACK_WIDTH; 
	playerPosition = 0; 
	
	/* ==== Level Editing Guide ===============
	Level creation is done by adding to or editing the switch statement below
	
	You can add as many levels as you want but you must have a "case"  
	for each level. The case numbers must start at 0 and go up without skipping any numbers.
	
	Don't edit case 0 or the last (boss) level. They are special cases and editing them could
	break the code.
	
	TWANG uses a virtual 1000 LED grid. It will then scale that number to your strip, so if you
	want something in the middle of your strip use the number 500. Consider the size of your strip
	when adding features. All time values are specified in milliseconds (1/1000 of a second)
	
	You can add any of the following features.
	
	Enemies: You add up to 10 enemies with the spawnEnemy(...) functions.
		spawnEnemy(position, direction, speed, wobble);
			position: Where the enemy starts 
			direction: If it moves, what direction does it go 0=down, 1=away
			speed: How fast does it move. Typically 1 to 4.
			wobble: 0=regular movement, 1=bouncing back and forth use the speed value
				to set the length of the wobble.
				
	Spawn Pools: This generates and endless source of new enemies. 2 pools max
		spawnPool[index].Spawn(position, rate, speed, direction, activate);
			index: You can have up to 2 pools, use an index of 0 for the first and 1 for the second.
			position: The location the enemies with be generated from. 
			rate: The time in milliseconds between each new enemy
			speed: How fast they move. Typically 1 to 4.
			direction: Directions they go 0=down, 1=away
			activate: The delay in milliseconds before the first enemy
			
	Lava: You can create 4 pools of lava.
		spawnLava(left, right, ontime, offtime, offset, state, grow, flow);
			left: the lower end of the lava pool
			right: the upper end of the lava pool
			ontime: How long the lave stays on.
			offset: the delay before the first switch
			state: does it start on or off
			grow: This specifies the rate of growth. Use 0 for no growth. Reasonable growth is 0.1 to 0.5
			flow: This specifies the rate/direction of flow. Reasonable numbers are 0.2 to 0.8 
	
	Conveyor: You can create 2 conveyors.
		spawnConveyor(startPoint, endPoint, direction)
			startPoint: The close end of the conveyor
			endPoint: The far end of the conveyor
			direction(speed): positive = away, negative = towards you (must be less than +/- player speed)
	
	===== Other things you can adjust per level ================ 
	
		Player Start position:
			playerPosition = xxx; 
				
			
		The size of the TWANG attack
			attack_width = xxx;
					
	
	*/
	switch(levelNumber){
	case 0: // basic introduction 
		playerPosition = 200;			
		spawnEnemy(1, 0, 0, 0);					
		break;
	case 1:
		// Slow moving enemy			
		spawnEnemy(900, 0, 1, 0);	
		break;
	case 2:	
		// Spawning enemies at exit every 2 seconds		
		spawnPool[0].Spawn(1000, 3000, 2, 0, 0);
		break;
	case 3:
		// Lava intro
		spawnLava(400, 490, 2000, 2000, 0, Lava::OFF, 0, 0);
		spawnEnemy(350, 0, 1, 0);
		spawnPool[0].Spawn(1000, 5500, 3, 0, 0);
		break;		
	case 4:
	    // intro to moving lava (down)
		spawnLava(400, 490, 2000, 2000, 0, Lava::OFF, 0, -0.5);
		spawnEnemy(350, 0, 1, 0);
		spawnPool[0].Spawn(1000, 5500, 3, 0, 0);
		break;
	case 5:		
		// lava spreading
		spawnLava(400, 450, 2000, 2000, 0, Lava::OFF, 0.25, 0);
		spawnEnemy(350, 0, 1, 0);
		spawnPool[0].Spawn(1000, 5500, 3, 0, 0);	
		break;
	case 6:	
		// Sin wave enemy				
		spawnEnemy(700, 1, 7, 275);
		spawnEnemy(500, 1, 5, 250);	
		break;
	case 7:
		// Sin enemy swarm
		spawnEnemy(700, 1, 7, 275);
		spawnEnemy(500, 1, 5, 250);
		
		spawnEnemy(600, 1, 7, 200);
		spawnEnemy(800, 1, 5, 350);
		
		spawnEnemy(400, 1, 7, 150);
		spawnEnemy(450, 1, 5, 400);		
		break;	
    case 8:
		// lava moving up
		playerPosition = 200;
		spawnLava(10, 180, 2000, 2000, 0, Lava::OFF, 0, 0.5);
		spawnEnemy(350, 0, 1, 0);
		spawnPool[0].Spawn(1000, 5500, 3, 0, 0);
		break;
	case 9:
		// Conveyor
		spawnConveyor(100, 600, -6);
		spawnEnemy(800, 0, 0, 0);
		break;
	case 10:
		// Conveyor of enemies
		spawnConveyor(50, 1000, 6);
		spawnEnemy(300, 0, 0, 0);
		spawnEnemy(400, 0, 0, 0);
		spawnEnemy(500, 0, 0, 0);
		spawnEnemy(600, 0, 0, 0);
		spawnEnemy(700, 0, 0, 0);
		spawnEnemy(800, 0, 0, 0);
		spawnEnemy(900, 0, 0, 0);
		break;
	case 11:
		// lava spread and fall
		spawnLava(400, 450, 2000, 2000, 0, Lava::OFF, 0.2, -0.5);
		spawnEnemy(350, 0, 1, 0);
		spawnPool[0].Spawn(1000, 5500, 3, 0, 0);
		break;
	case 12:   // spawn train;		
		spawnPool[0].Spawn(900, 1300, 2, 0, 0);					
		break;
	case 13:   // spawn train skinny attack width;
		attack_width = 32;
		spawnPool[0].Spawn(900, 1800, 2, 0, 0);
		break;
	case 14:  // evil fast split spawner
		spawnPool[0].Spawn(550, 1500, 2, 0, 0);
		spawnPool[1].Spawn(550, 1500, 2, 1, 0);
		break;
	case 15: // split spawner with exit blocking lava
		spawnPool[0].Spawn(500, 1200, 2, 0, 0);
		spawnPool[1].Spawn(500, 1200, 2, 1, 0);		
		spawnLava(900, 950, 2200, 800, 2000, Lava::OFF, 0, 0);
		break;
	case 16:
		// Lava run
		spawnLava(195, 300, 2000, 2000, 0, Lava::OFF, 0, 0);
		spawnLava(400, 500, 2000, 2000, 0, Lava::OFF, 0, 0);
		spawnLava(600, 700, 2000, 2000, 0, Lava::OFF, 0, 0);
		spawnPool[0].Spawn(1000, 3800, 4, 0, 0);
		break;
	case 17:
		// Sin enemy #2 practice (slow conveyor)
		spawnEnemy(700, 1, 7, 275);
		spawnEnemy(500, 1, 5, 250);
		spawnPool[0].Spawn(1000, 5500, 4, 0, 3000);
		spawnPool[1].Spawn(0, 5500, 5, 1, 10000);
		spawnConveyor(100, 900, -4);
		break;
	case 18:
		// Sin enemy #2 (fast conveyor)
		spawnEnemy(800, 1, 7, 275);
		spawnEnemy(700, 1, 7, 275);
		spawnEnemy(500, 1, 5, 250);			
		spawnPool[0].Spawn(1000, 3000, 4, 0, 3000);
		spawnPool[1].Spawn(0, 5500, 5, 1, 10000);
		spawnConveyor(100, 900, -6);
		break;
	case 19: // (don't edit last level)
		// Boss this should always be the last level			
		spawnBoss();
		break;
	}
	stageStartTime = millis();
	stage = PLAY;
}

void spawnBoss(){
	lastLevel = true;
	boss.Spawn();	
	moveBoss();
}

void moveBoss(){
	int spawnSpeed = 1800;
	if(boss._lives == 2) spawnSpeed = 1600;
	if(boss._lives == 1) spawnSpeed = 1000;
	spawnPool[0].Spawn(boss._pos, spawnSpeed, 3, 0, 0);
	spawnPool[1].Spawn(boss._pos, spawnSpeed, 3, 1, 0);
}

/* ======================== spawn Functions =====================================

   The following spawn functions add items to pools by looking for an unactive
   item in the pool. You can only add as many as the ..._COUNT. Additonal attemps 
   to add will be ignored.   
   
   ==============================================================================
*/
void spawnEnemy(int pos, int dir, int speed, int wobble){
    for(int e = 0; e<ENEMY_COUNT; e++){  // look for one that is not alive for a place to add one
        if(!enemyPool[e].Alive()){
            enemyPool[e].Spawn(pos, dir, speed, wobble);
            enemyPool[e].playerSide = pos > playerPosition?1:-1;
            return;
        }
    }
}

void spawnLava(int left, int right, int ontime, int offtime, int offset, int state, float grow, float flow){
    for(int i = 0; i<LAVA_COUNT; i++){
        if(!lavaPool[i].Alive()){
            lavaPool[i].Spawn(left, right, ontime, offtime, offset, state, grow, flow);
            return;
        }
    }
}

void spawnConveyor(int startPoint, int endPoint, int dir){
    for(int i = 0; i<CONVEYOR_COUNT; i++){
        if(!conveyorPool[i]._alive){
            conveyorPool[i].Spawn(startPoint, endPoint, dir);
            return;
        }
    }
}

void cleanupLevel(){
    for(int i = 0; i<ENEMY_COUNT; i++){
        enemyPool[i].Kill();
    }
    for(int i = 0; i<PARTICLE_COUNT; i++){
        particlePool[i].Kill();
    }
    for(int i = 0; i<SPAWN_COUNT; i++){
        spawnPool[i].Kill();
    }
    for(int i = 0; i<LAVA_COUNT; i++){
        lavaPool[i].Kill();
    }
    for(int i = 0; i<CONVEYOR_COUNT; i++){
        conveyorPool[i].Kill();
    }
    boss.Kill();
}

void levelComplete(){
    stageStartTime = millis();
    stage = WIN;
	
	if (lastLevel) {
		stage = BOSS_KILLED;
	}
	if (levelNumber != 0)  // no points for the first level
	{			
		score = score + (lives * 10);  // 
	}    
}

void nextLevel(){		
	levelNumber ++;
	
	if(lastLevel)	{
		stage = STARTUP;
		stageStartTime = millis();
		lives = user_settings.lives_per_level;
		
	}
	else {
		lives = user_settings.lives_per_level;
		loadLevel();
	}
}

void gameOver(){

    levelNumber = 0;
    loadLevel();
}

void die(){
    playerAlive = 0;
    if(levelNumber > 0) 
		lives --; 
	
    if(lives == 0){
       stage = GAMEOVER;
       stageStartTime = millis();
    }
    else
    {
      for(int p = 0; p < PARTICLE_COUNT; p++){
          particlePool[p].Spawn(playerPosition);
      }
      stageStartTime = millis();
      stage = DEAD;
    }
    killTime = millis();
}

// ----------------------------------
// -------- TICKS & RENDERS ---------
// ----------------------------------
void tickStartup(long mm)
{
  FastLED.clear();
  if(stageStartTime+STARTUP_WIPEUP_DUR > mm) // fill to the top with green
  {
    int n = _min(map(((mm-stageStartTime)), 0, STARTUP_WIPEUP_DUR, 0, user_settings.led_count), user_settings.led_count);  // fill from top to bottom
    for(int i = 0; i<= n; i++){     
      leds[i] = CRGB(0, 255, 0);
    }   
  }
  else if(stageStartTime+STARTUP_SPARKLE_DUR > mm) // sparkle the full green bar    
  {
    for(int i = 0; i< user_settings.led_count; i++){    
      if(random8(30) < 28)
        leds[i] = CRGB(0, 255, 0);  // most are green
      else {
        int flicker = random8(250);
        leds[i] = CRGB(flicker, 150, flicker); // some flicker brighter
      }
    }
    
  }
  else if (stageStartTime+STARTUP_FADE_DUR > mm) // fade it out to bottom
  {
    int n = _max(map(((mm-stageStartTime)), STARTUP_SPARKLE_DUR, STARTUP_FADE_DUR, 0, user_settings.led_count), 0);  // fill from top to bottom
    int brightness = _max(map(((mm-stageStartTime)), STARTUP_SPARKLE_DUR, STARTUP_FADE_DUR, 255, 0), 0);
    // for(int i = 0; i<= n; i++){    
       
      // leds[i] = CRGB(0, brightness, 0);
    // }
    for(int i = n; i< user_settings.led_count; i++){   
       
      leds[i] = CRGB(0, brightness, 0);
    }   
  } 
  SFXFreqSweepWarble(STARTUP_FADE_DUR, millis()-stageStartTime, 40, 400, 20);
  
}
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

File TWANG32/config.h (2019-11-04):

/*
	TWANG32 - An ESP32 port of TWANG
	(c) B. Dring 3/2018
	License: Creative Commons 4.0 Attribution - Share Alike	
	
	TWANG was originally created by Critters
	https://github.com/Critters/TWANG
	
	Basic hardware definitions
	
	Light Strip Notes:
	
	Noepixel / WS2812
		- Low Cost
		- You might already have a strip.
		- No Clock Line - This means a fixed and relatively slow data rate and only shorter strips can be used
		- Poor Dynamic Range - The low end of brightness is basically not visible
	Dotstar (Highly recommended)
	  - Higher Cost
		- Higher speed - Longer strips can be used.
		- Great dynamic range, so lower levels and more colors can be used.
	

*/

#ifndef CONFIG_H
	#define CONFIG_H

#define DATA_PIN        16
#define CLOCK_PIN       17

/* Game is rendered to this and scaled down to your strip.
 This allows level definitions to work on all strip lengths  */
#define VIRTUAL_LED_COUNT 1000  

// what type of LED Strip....uncomment to define only one of these
#define USE_APA102

//#define USE_NEOPIXEL

// Check to make sure LED choice was done right
#if !defined(USE_NEOPIXEL) && !defined(USE_APA102)
	#error "You must have USE_APA102 or USE_NEOPIXEL defined in config.h"
#endif

#if defined(USE_NEOPIXEL) && defined(USE_APA102)
	#error "Both USE_APA102 and USE_NEOPIXEL are defined in config.h. Only one can be used"
#endif

#ifdef USE_APA102
  #define LED_TYPE        			APA102
  #define LED_COLOR_ORDER      	BGR // typically this will be the order, but switch it if not
  #define CONVEYOR_BRIGHTNESS 	8
  #define LAVA_OFF_BRIGHTNESS 	4
	#define MAX_LEDS   						VIRTUAL_LED_COUNT // these LEDS can handle the max
	#define MIN_REDRAW_INTERVAL  	1000.0 / 60.0    // divide by frames per second..if you tweak, adjust player speed
#endif

#ifdef USE_NEOPIXEL
  #define LED_TYPE        		 	NEOPIXEL
	#define CONVEYOR_BRIGHTNESS 	40  // low neopixel values are nearly off, Neopixels need a higher value
	#define LAVA_OFF_BRIGHTNESS  	15   // low neopixel values are nearly off, Neopixels need a higher value
	#define MAX_LEDS 						 	288  // Neopixels cannot handle the framerate
	#define MIN_REDRAW_INTERVAL  	1000.0 / 60.0    // divide by frames per second..if you tweak adjust player speed
#endif
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

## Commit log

2018-03-19 First upload
    Basic port complete - ESP32 specific features coming soon
2018-03-22 Added web server and serial port setup
    - Access game stats via wifi access point and web server
    - Setup game preferences via serial port (EEPROM issue causes
    crashes...help me fix). Does not affect game normal play.
    - Updated to recent stuff on Arduino port.
    [TWANG32.ino, settings.h]
2018-03-27 Fixed EEPROM Crashing
    Turning off the sound interrupt durring EEPROM writing fixed the
    problem.
    [TWANG32.ino, settings.h]
2018-03-31 Added strip length adjustment via serial and wifi. Working toward "no compile" required for any setup.
    - fixed bug in settings when initial read failed. It was
    trying to
    turn off the sound timer while it was still NULL
    - Number of LEDs is
    now adjustable via serial and wifi. Woot, no
    recompile just to
    change strip length.
    - A little refactoring so Wifi and Serial
    interfaces can share
    some code.
    - Added Refresh button to web page
    [TWANG32.ino, settings.h]
2018-04-03 Improved web page and fixed some bugs.
    - JOYSTICK_DEBUG was left on...turned it off
    - Web page fields now have
    type='number' so they bring up a number keyboard
    - Refresh the
    brightness when it changes.
    [TWANG32.ino, settings.h]
2018-04-29 Move sketch to appropriately named subfolder
    The Arduino IDE requires that a sketch be located in a folder of the same name. Although the name of the repository does match the sketch name, when GitHub's popular Clone or download > Download ZIP 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
    When opening a file that does not meet this sketch/folder name matching requirement the Arduino IDE presents a dialog:
    The file "TWANG32.ino" needs to be inside a sketch folder named "TWANG32".
    Create this folder, move the file, and continue?
    After clicking "OK" the Arduino IDE currently moves only the file TWAN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
2018-05-01 Updates and New Features
    - More Screen Savers
    - Better looking
    reset after gameover
    - Better looking restart after boss kill
    -
    Updated readme with video and latest info
    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
    [TWANG32.ino]
2018-06-29 Fixing Neoplixel Version
    The Neopixel version was not working. I updated to the latest FastLED
    library that uses the RMT feature and a second core. I also updated the
    code to make it easier to deal with the differences between the Neopixel
    and Dotstar versions.
    [TWANG32.ino, config.h, settings.h]
2019-06-06 Added additional sourcee files
    [BoardOutline.gbr, Bottom.gbr, BottomMask.gbr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]
2019-10-10 Remove double /* to fix compiler error
    [TWANG32.ino]
2019-11-03 Updates, new terrifying lava options.
    - Lava now has flow and growth options
    - APA102 is now the default
    - Changed the default wifi password
    - Fix #include (capitalization error)
    [TWANG32.ino, config.h]
2019-11-14 Fix inLava detection
    If LP._right is the same as pos the user is still in lava :)
    [TWANG32.ino]
2020-02-06 Adding PCB BOM
    [twang32_pcb_bom.csv]
